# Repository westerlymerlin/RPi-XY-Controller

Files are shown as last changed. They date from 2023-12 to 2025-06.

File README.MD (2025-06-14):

# X-Y Controller

### X-Y Controller is a python app that can operate 24v stepper motors and is controlled via an HTTP API

Functional description and setup instructions are available in the file: [README.pdf](./README.pdf)

Python module documentation can be found in the folder: [docs](./docs/readme.md)

Change log can be found in the file [changelog.txt](./changelog.txt)

`app.py`			    Flask application that manages the API 

----------------------------------------------------

`stepperontrol.py`		Controls X-Y stage via bipolar stepper motors and an ADC controller to read positional information. 

### JSON Commands

`{'getxystatus', 1}` Return the current locations of the x and y steppers
 
`{'xmove', n}` move x stepper n steps (-n for backwards) (if n=0 then stop)

`{'ymove', n}` move y stepper n steps (-n for backwards) (if n=0 then stop)

`{'xmoveto', f}` move x stepper to position f (float)

`{'ymoveto', f}` move y stepper to position f (float)

&nbsp;   
&nbsp;    
&nbsp;  
&nbsp;   
&nbsp;   
&nbsp;   
--------------

#### Copyright (C) 2025 Gary Twinn

This program is free software: you can redistribute it and/or modify  
it under the terms of the GNU General Public License as published by  
the Free Software Foundation, either version 3 of the License, or  
(at your option) any later version.  

This program is distributed in the hope that it will be useful,  
but WITHOUT ANY WARRANTY; without even the implied warranty of  
MERCHANTABILITY or FITNESS FOR A PARTICULAR PURPOSE. See the  
GNU General Public License for more details.  

You should have received a copy of the GNU General Public License  
along with this program. If not, see <https://www.gnu.org/licenses/>.

Author:  Gary Twinn  
Repository:  [github.com/westerlymerlin](https://github)

-------------

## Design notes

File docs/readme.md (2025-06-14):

# Module Documentation

This document contains the documentation for all the modules in this project.

---

## Contents

[app](./app.md)  
X-Y Controller Web Application

A Flask-based web application that provides both a user interface and API endpoints
for controlling and monitoring an X-Y positioning system. The application offers:

- Status monitoring via web interface
- API endpoints for programmatic control (API key required)
- Self-test functionality for system validation
- Access to various log files (application, Gunicorn, system)
- System information including CPU temperature and running threads

The application is designed to be run by Gunicorn in a production environment,
but can also be run directly for development purposes.

Routes:
  - / : Main status page
  - /api : API endpoint for programmatic control (POST, requires API key)
  - /selftest : Runs a system self-test
  - /pylog : Displays application logs
  - /guaccesslog : Displays Gunicorn access logs
  - /guerrorlog : Displays Gunicorn error logs
  - /syslog : Displays system logs

Configuration is managed through settings imported from app_control.

[app_control](./app_control.md)  
Settings module, reads the settings from a settings.json file. If it does not exist or a new setting
has appeared it will creat from the defaults in the initialise function.

[logmanager](./logmanager.md)  
logmanager, setus up application logging. use the **logger** property to
write to the log.

[steppercontrol](./steppercontrol.md)  
Stepper Motor Control System for XY Table

This module provides classes and functions to control an XY positioning table
using stepper motors with ADC feedback for position tracking. It includes:

- Position tracking via ADC readings
- Stepper motor control with multiple movement modes (step, continuous, targeted)
- Web API endpoints for remote control
- Self-test capabilities for system diagnostics

The system uses GPIO pins on a Raspberry Pi to control the stepper motors and
reads position data through an ADC interface. It supports both programmatic
control and web-based interaction through status reporting functions.

Dependencies:
    - RPi.GPIO: For GPIO control
    - ADCPi: For analog position reading
    - threading: For non-blocking motor control

---

-------
#### Copyright (C) 2025 Gary Twinn  

This program is free software: you can redistribute it and/or modify
it under the terms of the GNU General Public License as published by
the Free Software Foundation, either version 3 of the License, or
(at your option) any later version.

This program is distributed in the hope that it will be useful,
but WITHOUT ANY WARRANTY; without even the implied warranty of
MERCHANTABILITY or FITNESS FOR A PARTICULAR PURPOSE. See the
GNU General Public License for more details.  
  
You should have received a copy of the GNU General Public License
along with this program. If not, see <https://www.gnu.org/licenses/>.  
  
  ##### Author: Gary Twinn  
  
 -------------

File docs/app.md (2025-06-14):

# None

# app

X-Y Controller Web Application

A Flask-based web application that provides both a user interface and API endpoints
for controlling and monitoring an X-Y positioning system. The application offers:

- Status monitoring via web interface
- API endpoints for programmatic control (API key required)
- Self-test functionality for system validation
- Access to various log files (application, Gunicorn, system)
- System information including CPU temperature and running threads

The application is designed to be run by Gunicorn in a production environment,
but can also be run directly for development purposes.

Routes:
  - / : Main status page
  - /api : API endpoint for programmatic control (POST, requires API key)
  - /selftest : Runs a system self-test
  - /pylog : Displays application logs
  - /guaccesslog : Displays Gunicorn access logs
  - /guerrorlog : Displays Gunicorn error logs
  - /syslog : Displays system logs

Configuration is managed through settings imported from app_control.

## subprocess

## enumerate\_threads

## Flask

## render\_template

## jsonify

## request

## httpstatus

## parsecontrol

## apistatus

## runselftest

## VERSION

## settings

## logger

#### app

#### read\_cpu\_temperature

```python
def read_cpu_temperature()
```

Reads the CPU temperature from the file specified in the settings and converts
it to Celsius.

Reads the raw CPU temperature value from the file path defined in the settings
dictionary under the 'cputemp' key. The value is retrieved as a string,
converted to a floating-point number, divided by 1000 to get the temperature
in Celsius, rounded to one decimal place, and returned.

Returns:
    float: The CPU temperature in Celsius.

Raises:
    KeyError: If the 'cputemp' key is missing from the settings dictionary.
    FileNotFoundError: If the specified file does not exist.
    IOError: If there is an error reading the file.

#### read\_reversed\_lines

```python
def read_reversed_lines(path)
```

Reads lines from a file, reverses their order, and returns the reversed list of lines.

Summary:
This function reads all the lines from a specified file, reverses the order of those lines,
and returns the reversed list. The file is expected to be encoded in UTF-8.

Args:
    path (str): The path to the file from which lines will be read.

Returns:
    list[str]: A list containing the lines from the file in reversed order.

#### threadlister

```python
def threadlister()
```

Get the list of active threads with their names and native IDs.

This function gathers all currently active threads, retrieves their names
and native IDs, and organizes them into a list. Each thread is represented
as a sublist containing its name and native ID. This is useful for debugging
or monitoring thread activity in the application.

Returns:
    List[List[str, int]]: A list of active threads where each thread is
    represented as a list containing its name (str) and native ID (int).

#### index

```python
@app.route('/')
def index()
```

Handles the root route of the application, retrieves CPU temperature, and renders
the main index page with relevant data such as locations, application version,
CPU temperature, and active threads.

Returns:
    str: Rendered HTML template for the index page.

#### api

```python
@app.route('/api', methods=['POST'])
def api()
```

Handles API requests for executing commands on specific items by verifying the provided API key.

The function is intended to handle POST requests to the '/api' endpoint. It verifies the validity of the
API key provided in the request headers before processing the request. If the API key is valid, it extracts
the required parameters from the JSON payload (item and command), processes the command, and returns the API
status. If the key is missing or invalid, it logs the attempt and returns an appropriate HTTP response.

The function also handles malformed JSON messages gracefully by returning an error response.

Returns:
    JSONResponse: A JSON-formatted response containing the API status with a status code of 201 if the request
    is processed successfully.
    String: An error message with an appropriate HTTP status code if the API key is missing, invalid, or the
    request JSON is malformed.

#### selftest

```python
@app.route('/selftest')
def selftest()
```

Handles the self-test endpoint for a web application. This function triggers
a self-test operation to assess system functionality and provides a response
indicating that the test process has started. Users are instructed to review
logs and the front panel for results.

Returns
-------
str
    A message indicating that the self-test operation has started, along with
    a link to access system logs.

#### showplogs

```python
@app.route('/pylog')
def showplogs()
```

Handles the retrieval and rendering of application logs in reverse order.

This function is mapped to the '/pylog' endpoint and fetches the log entries
for a Data Node from the specified log file. The logs are reversed so that
recent entries are displayed first. It then renders an HTML template with
the logs, title, and version information, providing a user interface to
analyze the log data.

Returns:
    Response: Renders an HTML template populated with log data, log title,
              and version details.

#### showgalogs

```python
@app.route('/guaccesslog')
def showgalogs()
```

Displays the Gunicorn access log by reading and reversing the lines of the
log file. The log is formatted into a web page showing the most recent
entries first.

Returns
-------
str
    Rendered HTML template for displaying the Gunicorn access log.

Raises
------
KeyError
    If 'gunicornpath' is not defined in the settings dictionary.

#### showgelogs

```python
@app.route('/guerrorlog')
def showgelogs()
```

Displays the Gunicorn error log.

This function handles the web endpoint for retrieving and displaying the
Gunicorn error log file. It reads the log file in reverse order, formats
it, and renders it in an HTML page for easy viewing.

Returns:
    Response: A rendered HTML page containing the Gunicorn error log.

#### showslogs

```python
@app.route('/syslog')
def showslogs()
```

Display the Raspberry Pi system logs along with CPU temperature.

Opens and reads the system log file and CPU temperature from the specified
file path within the `settings` dictionary. Retrieves the most recent 200
log entries using the `journalctl` command. The log entries are reversed to
show the latest log entries first. The CPU temperature data is converted
and rounded to a single decimal point before being rendered in the HTML
template.

Raised exceptions during file access or subprocess execution are not
explicitly handled here.

Returns:
    flask.Response: Rendered HTML template containing system log entries,
    CPU temperature, and the software version.

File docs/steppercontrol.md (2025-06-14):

# None

# steppercontrol

Stepper Motor Control System for XY Table

This module provides classes and functions to control an XY positioning table
using stepper motors with ADC feedback for position tracking. It includes:

- Position tracking via ADC readings
- Stepper motor control with multiple movement modes (step, continuous, targeted)
- Web API endpoints for remote control
- Self-test capabilities for system diagnostics

The system uses GPIO pins on a Raspberry Pi to control the stepper motors and
reads position data through an ADC interface. It supports both programmatic
control and web-based interaction through status reporting functions.

Dependencies:
    - RPi.GPIO: For GPIO control
    - ADCPi: For analog position reading
    - threading: For non-blocking motor control

## sleep

## os

## Timer

## GPIO

## ADCPi

## logger

## PositionClass Objects

```python
class PositionClass()
```

Manages the x and y positions obtained from ADC readings.

The class periodically reads position values from ADC inputs and
provides the location data along specified axes. It initializes
and starts a timer thread to fetch the positional data continuously.

#### \_\_init\_\_

```python
def __init__()
```

#### getpositions

```python
def getpositions()
```

Reads positional voltage data from an ADC and calculates the x and y positions
relative to a 2.5V reference. This is a continuous process that updates the
object's x and y attributes every 0.25 seconds while the ADC object is valid.

#### location

```python
def location(table_axis)
```

Determines and returns the location value along a specified axis.

This method evaluates the given table axis ('x' or 'y') and
returns the corresponding coordinate value. If the provided axis
is invalid, a default value of -99.99 is returned.

Args:
    table_axis: A string indicating the axis ('x' or 'y').

Returns:
    float: The coordinate value for the specified axis, or -99.99
    if the axis is invalid.

## StepperClass Objects

```python
class StepperClass()
```

Represents a stepper motor controller, enabling precise control over the stepper
motor's movement, configuration, and operational parameters.

This class provides methods for initializing and controlling a stepper motor's
movement such as stepping forward, stepping backward, stopping, or moving to
specific positions. It also supports setting GPIO channels, retrieving active
sequences, and managing limits for motor movement. The class incorporates
adjustable movement speeds (full speed or slow) and ensures proper handling of
stepper sequences during operation.

Attributes:
    axis: A string indicating the axis of operation for the stepper motor.
    seq: A list of lists, defining sequences for stepper coil activations.
    channela: An integer representing the GPIO channel for the first winding.
    channelaa: An integer representing the GPIO channel for the second winding.
    channelb: An integer representing the GPIO channel for the third winding.
    channelbb: An integer representing the GPIO channel for the fourth winding.
    sequenceindex: An integer representing the current sequence index of the motor.
    upperlimit: A float defining the maximum allowed position limit for movement.
    lowerlimit: A float defining the minimum allowed position limit for movement.
    sequence: An integer counter for the current movement sequence.
    pulsewidth: A float specifying the delay between steps, controlling speed.
    moving: A boolean flag indicating whether the motor is actively moving.

#### \_\_init\_\_

```python
def __init__()
```

#### setchannels

```python
def setchannels(a, aa, b, bb)
```

Sets up the channel attributes and configures them as output channels.

This method assigns input values to the corresponding channel attributes of
the object and configures the specified GPIO channels as outputs using the
GPIO setup method.

Args:
    a: The first channel to be assigned to 'channela'.
    aa: The second channel to be assigned to 'channelaa'.
    b: The third channel to be assigned to 'channelb'.
    bb: The fourth channel to be assigned to 'channelbb'.

#### listchannels

```python
def listchannels()
```

Returns a list of available channels.

This method retrieves and returns a list of channels available
within the current instance. It consolidates the individual channel
attributes defined in the object.

Returns:
    list: A list containing elements channela, channelaa, channelb,
    and channelbb.

#### current

```python
def current()
```

Returns the current element from the sequence based on the sequence index.
It retrieves the element at the position indicated by 'sequenceindex' from
the sequence stored in 'seq'.

Returns:
    The element in the sequence located at the index defined by attribute 'sequenceindex'.

#### movenext

```python
def movenext(fine=False)
```

Moves the axis motor to the next position within the defined range of movement.

This method increments the motor's sequence index to move the axis one step forward,
provided the current position of the motor's axis is less than the specified upper limit.
The movement can be divided between fine and coarse categories
based on whether the `fine` parameter is set to True or False.

Parameters:
    fine (bool, optional): If True, retains output state after a movement;
                           otherwise, resets the output state to zero.

#### moveprevious

```python
def moveprevious(fine=False)
```

Moves to the previous position along a defined axis.

This function decreases the position index by one step unit and
updates the output according to the current sequence. The sequence index
is updated in a circular manner. If fine movement is not required,
the output is reset to neutral after the step.

Args:
    fine (bool): If True, the movement is fine and does not reset the output
                 to neutral after stepping. Defaults to False.

#### stop

```python
def stop()
```

Stops the current movement and updates the sequence counter.

Stops the movement of the device or component by setting its moving status to
False and increments the sequence number. Logs the current position of the
device/component on the x and y axes. Outputs a signal to indicate the stop
state.

#### move

```python
def move(steps)
```

Moves a mechanism a specified number of steps in a defined sequence. The movement
can be either forward or backward depending on whether the step count is positive
or negative. The function halts movement if steps reach zero or if the moving
state becomes false. It includes a sequence update and enforces a delay between
steps based on a pulse width.

Parameters:
    steps (int): The number of steps to move. Positive values indicate forward
    movement, and negative values indicate backward movement.

#### moveslow

```python
def moveslow(steps)
```

Moves the object step-by-step in a specified direction. The method continues moving
the object one step at a time until the specified number of steps is completed or
movement is explicitly stopped. Movement is paused for a fixed time interval after
each step to simulate slow movement.

Parameters:
    steps (int): The number of steps to move. Positive values indicate forward
    movement; negative values indicate backward movement.

#### moveto

```python
def moveto(target)
```

Moves the axis to the specified target position within predefined limits. The method adjusts
the axis position step by step until it reaches the target position or a defined condition
occurs, such as exceeding a step counter threshold or passing the target position.

If the target position is outside the lower and upper limits, the operation will not
proceed. Step adjustments are made iteratively to ensure the axis reaches the closest
possible location to the target. The sequence number ensures the operation is associated
with the intended move command and prevents interference from other simultaneous commands.

Parameters
----------
target : float
    The desired position to which the axis is moved.

#### output

```python
def output(channels)
```

Controls the output state of specified GPIO channels using the provided channel states.

This function takes a list or tuple of four channel states and sets the associated
GPIO output for each corresponding channel. Each state in the list corresponds to
a specific GPIO channel, and the function utilizes the `output` method of the
GPIO module for assigning these states.

#### httpstatus

```python
def httpstatus()
```

Provides a function to generate a list containing rounded positional status.

The `httpstatus` function creates a dictionary containing the keys `xpos` and `ypos`, where the values
are the rounded versions of `positions.x` and `positions.y` respectively.
It then adds this dictionary into a list and returns it as the function output.

Returns:
    list: A list with a single dictionary containing `xpos` and `ypos` keys, with their corresponding
    values being rounded to four decimal points.

#### apistatus

```python
def apistatus()
```

Retrieve the current status of the system including positions and movement states.

This function compiles the current x and y positions of the system, along with
the movement status of stepper motors for both axes, into a dictionary.

Returns:
    dict: A dictionary containing the x and y positions, as well as movement
    states for both stepper motors.

#### parsecontrol

```python
def parsecontrol(item, command)
```

Parses the control command and executes the corresponding action, such as
moving a stepper motor or issuing a system restart. The function supports
multiple control commands and executes them in separate timer threads when
required.

Parameters:
item (str): The control item indicating the action type, such as 'xmove',
'ymove', 'xmoveto', 'ymoveto', or 'restart'.
command (str): The associated command or argument required for the action.

#### runselftest

```python
def runselftest()
```

Stops both motors and initiates a test sequence with a delay.

This function ensures that the motors are stopped prior to running
the self-test, providing a safe starting point for the test. A delay
of 10 seconds is introduced before beginning the test sequence. The
test sequence is executed in a separate thread.

#### reboot

```python
def reboot()
```

Reboots the system using an operating system command.

This function logs a warning message indicating that the system is
restarting and then executes the system's reboot command immediately.
This operation requires appropriate system permissions.

#### testsequence

```python
def testsequence()
```

Conducts a self-test sequence for channel x and channel y operations, verifying stepper motor
behaviors through various output states and movement actions. The function performs a series
of tests on both channels by setting their output states, moving them in forward and backward
directions, and ensuring their responses align with expected behavior.

#### positions

#### stepperx

#### steppery

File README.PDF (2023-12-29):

# X-Y Controller

Software Functional Requirements

By Gary Twinn

## Contents

Operating system | Error! Bookmark not defined.
Run Operating System Updates | Error! Bookmark not defined.
Install PIP3 for Python 3.x installation | Error! Bookmark not defined.
Install Flask installation | Error! Bookmark not defined.
Install Raspberry Pi GPIO Driver | Error! Bookmark not defined.
Download the XY-Controller application | Error! Bookmark not defined.
Copy the python files to the Pi | Error! Bookmark not defined.
Nginx installation | Error! Bookmark not defined.
Gunicorn for Python 3.x installation | Error! Bookmark not defined.

## List of Figures

## List of Tables

## Overview

The X-Y controller software consists of a python (Python Software Foundation, 2020) application to control the 2 stepper motors on the X-Y Stage of the Helium line.

The X-Y table consists of 2 Bipolar stepper motors to drive the table in two dimensions. A stepper motor consists of a pair of windings A-AA and B-BB surrounding a rotor containing permanent magnets (Figure 1)

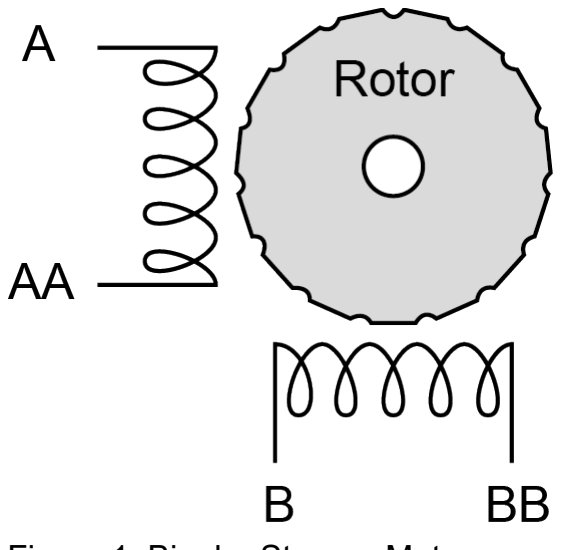
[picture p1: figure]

Figure 1: Bipolar Stepper Motor
The stepper motor is operated by applying a voltage across the A and B windings which causes the permanent magnets on the rotor to either attract or repel. The voltage is applied a with the positive to A and B and the negative to AA and BB. To move the rotor one winding will have the voltage reversed in turn. At each transition where the voltage is reversed on a winding the rotor will rotate 1.8° clockwise. By reversing the sequence the rotor will rotate anti-clockwise. By grounding both connections during of one winding between the reversals will cause the rotor to take a half step. Adding a delay between transitions will set a speed for the motor, a fast speed would have 25ms between transitions whereas a slower speed is used for accurately locating the laser over the sample.
A AA | B BB
0 | + | - | + | - Initial State
1 | + | - | - | + B reversal
2 | - | + | - | + A reversal
3 | - | + | + | - B revert
4 | + | - | + | - A revert
Table 1: Full step sequence for bipolar stepper motor

A AA | B BB
0 | + | - | + | - Initial State
1 | + | - | - | - ½ step ground B
2 | + | - | - | + B reversal
3 | - | - | - | + ½ step ground A
4 | - | + | - | + A reversal
5 | - | + | - | - ½ step ground B
6 | - | + | + | - B revert
7 | - | - | + | - ½ step ground A
8 | + | - | + | - A revert
Table 2: Half step sequence for bipolar stepper motor

There are two 2KΩ linear displacement sensors with a 50mm travel mounted on the x-y stage, one in each direction. By applying a voltage to each end of the sensor, the location of the wiper along the sensor can be determined. The travel along the planchet is 10.5mm in each of the X directions (from the origin) and 17.5mm from the origin in each of the Y directions.

The 2KΩ displacement sensor will have a reference voltage of +5.08 volts applied to one static connection, the other static connection will be held to 0V. That will give a voltage gradient along the 50mm of 0.1V per mm.

A joystick will be required for manual control of the X-Y table.
The computer required to control the valves will be a Raspberry Pi 4 (Raspberry PI Foundation, 2020), it will require a connector to break out the required 12 GPIO pins and connect to the driver boards.

Each stepper motor will be connected to 4 dedicated GPIO lines on the raspberry Pi computer. The valves run on 5V DC @ 1 A, so a driver circuit will be required to step up the voltage and current from the Pi. The linear

The Raspberry Pi computer will be controlled via a RESTful API listening on port 80 for a valid json message.

## Input Messages

Json messages in the following formats will be accepted:

Move in X direction to a location (voltage). Where n is a floating-point number between -2.5 and +2.5. Once started the stepper will move at a relative high speed (30 steps per second) until the position voltage is within 0.2V (~ 2mm) at which point it will slow to a rate of 10 steps a second until the position voltage is within 0.1V (~ 1mm). At 0.1V the rate will slow again to 3 steps per second until the desired position has just passed, at that point the stepper will reverse for 1 step to position as the table as accurately as possible with the stepper motors attached to the x-y stage.

{
"item": "xmoveto",
"command": n
}

Move in X direction nn steps. Where nn is a positive or negative integer depending on the direction or motor rotation. Sending a value of 0 will cause the stepper motor to halt immediately and disengage power to the x direction stepper motor.

{
"item": "xmove",
"command": nn
}

Move in Y direction to a location (voltage). Where n is a floating-point number between -2.5 and +2.5.

{
"item": "ymoveto",
"command": n
}

Move in Y direction nn steps. Where nn is a positive or negative integer depending on the direction or motor rotation. Sending a value of 0 will cause the stepper motor to halt immediately and disengage power to the y direction stepper motor.

{
"item": "ymove",
"command": nn
}

## Output Messages

Following any valid command, the following query is returned: (ss = open or closed)

{
"xpos": xnn,
"ypos": ynn
}

Where xnn and ynn are floating point numbers denoting the output voltages of each displacement sensor.

## Control to GPIO assignment

Control | Designation | Connector | Designation | Control
| 3v3 | 1 | 2 | 5v
i2c Data | GPIO 02 | 3 | 4 | 5v
i2c Clock | GPIO 03 | 5 | 6 | GND
GP clock | GPIO 04 | 7 | 8 | GPIO 14
| GND | 9 | 10 | GPIO 15
X Stepper A | GPIO 17 | 11 | 12 | GPIO 18 | Y Stepper A
X Stepper AA | GPIO 27 | 13 | 14 | GND
X Stepper B | GPIO 22 | 15 | 16 | GPIO 23 | Y Stepper AA
| 3v3 | 17 | 18 | GPIO 24 | Y Stepper B
| GPIO 10 | 19 | 20 | GND
Y Stepper BB | GPIO 09 | 21 | 22 | GPIO 25
Joystick X+ | GPIO 11 | 23 | 24 | GPIO 08
| GND | 25 | 26 | GPIO 07
| GPIO 00 | 27 | 28 | GPIO 01
| GPIO 05 | 29 | 30 | GND
| GPIO 06 | 31 | 32 | GPIO 12 | Ready LED
X Stepper BB | GPIO 13 | 33 | 34 | GND
| GPIO 19 | 35 | 36 | GPIO 16 | Joystick X-
Joystick Speed | GPIO 26 | 37 | 38 | GPIO 20 | Joystick Y+
| GND | 39 | 40 | GPIO 21 | Joystick Y-
Table 3: Control to GPIO Assignments
The above assignments are based on a raspberry Pi 4B. GPIO channels in green are available and remain at 0v during the Pi boot up.

Once the boot sequence has completed and the software has started the final command on the initialising function will be to light the “Ready LED” to give a visual indication the raspberry PI has booted and is ready to accept commands on the REST api.

The Joystick connections will need to be set to inputs with an internal pull-up resistor, thus requiring a connection to GND in order to trigger movement.

## Driver circuit and power supply

The Pi 4B uses a 5v power supply provided via a USB-C connector. A 5V power supply rated at 3A will be required.

The GPIO outputs are 3.3v at 50mA, the stepper motors require 5V DC @1A to rotate but the current could increase above 1A under a heavy load. In order to drive the 4 windings in the stepper motors a driver circuit will be required to step up the voltage and current (Figure 2). A power supply with a continuous rating of 6.0A will be required to ensure reliability. To protect the Pi Zero from any voltage spikes that may be generated by the steppers, or a faulty component on the hight voltage/high current side of the driver, an opto-isolator will be required to provide full electrical isolation between the Pi and the driver circuit.

The stepper motors will be driven via an integrated circuit containing four Metal Oxide Field Effect Transistors (MOSFET). MOSFETs have a very low forward voltage once switched on and have a high-power capacity. As the stepper windings are inductive loads, when the power is removed from the windings there is a chance voltage spikes will be induced into the circuit so a Schottky diode will protect the MOSFET and opto-isolator.

An analogue to digital convertor will be required to read the voltage from the position sensors and turn it into a signal the Raspberry Pi computer can read. The ADC chosen was from Able Electronics (Able Electronics UK 2020) and a resolution of 12 bits was chosen giving the controller the ability to detect 4096 voltage steps. Given that a 50mm travel on the position sensor would give a voltage reading between 0V and 5V the voltage to distance conversion is 0.1V / mm. Dividing the 5V supply by the step resolution steps gives 0.0012V per step or a resolution of 0.012 mm.

The driver circuits will need to be housed in an enclosure that has external connectors for the mains supply, ethernet cable and connectors for the x and y steppers, x and y position sensors and joystick cables. It must have ventilation holes to prevent the Raspberry Pi’s, power supplies or driver MOS-FET transistors overheating. Indicator lights should show the status of the 5v PSU for the Raspberry Pi, the 5V Stepper PSU and the ready light to show the software has started.

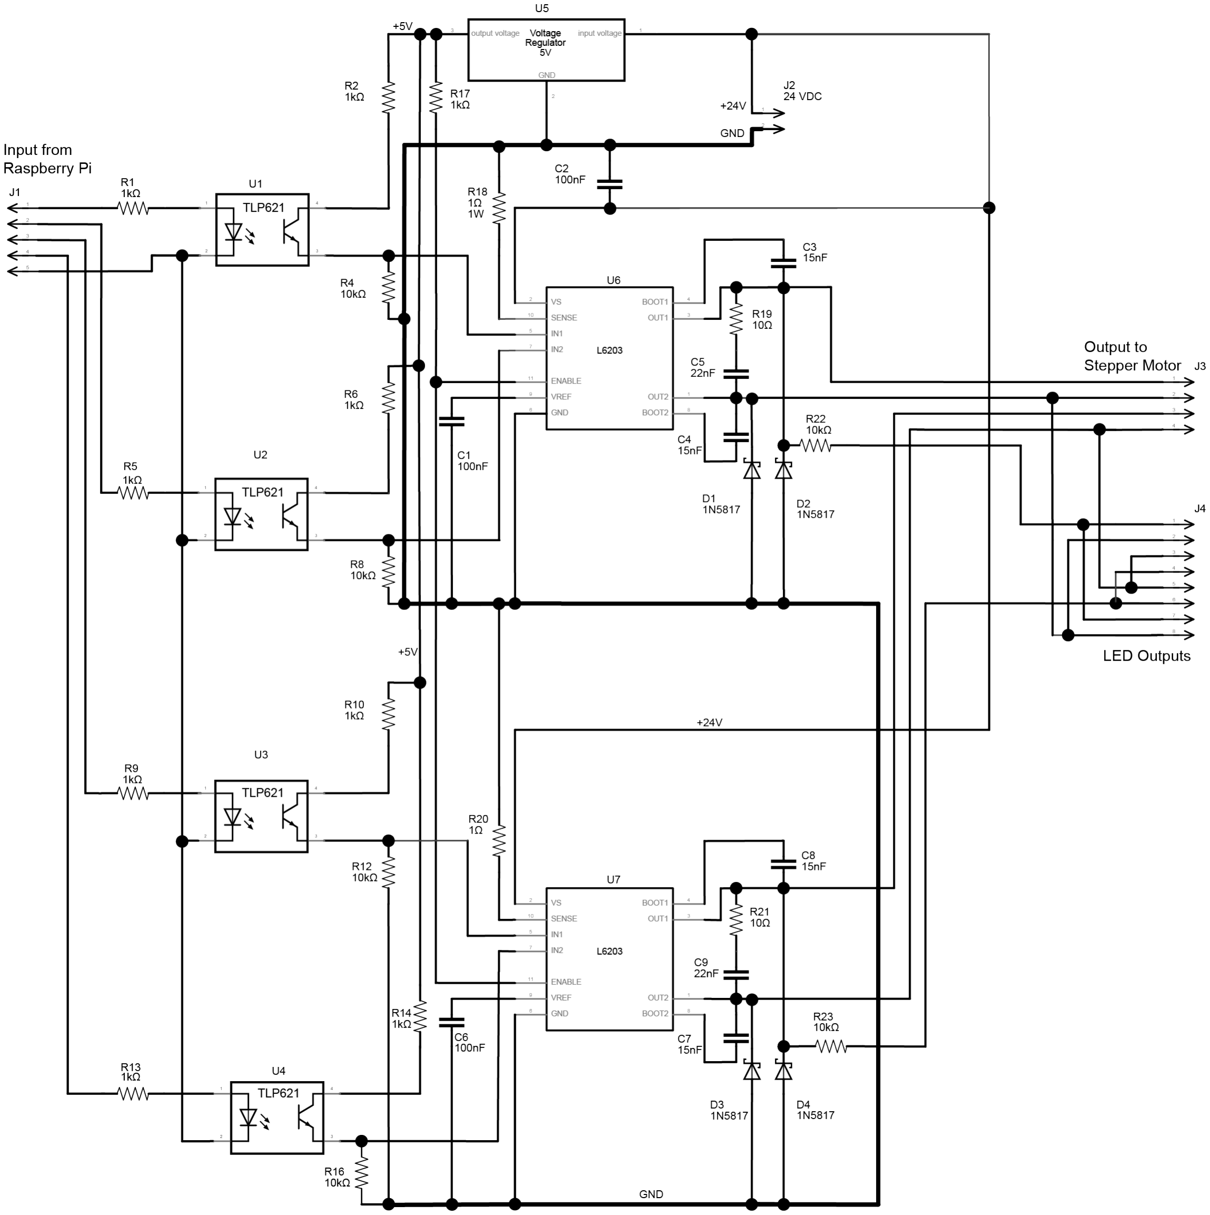
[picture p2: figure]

Figure 2: Schematic for a valve / stepper driver board

## Web interface

As well as accessing the status of the valves via the RESTful API a read-only web interface that can be accessed directly from a browser is will be available to view the valve status, application and web server logs.

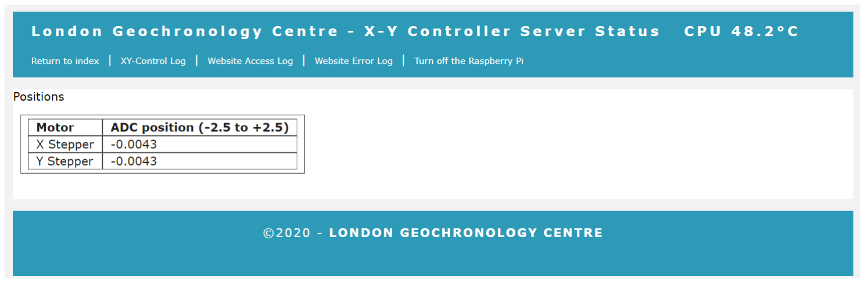
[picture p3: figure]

Figure 3: Web status page

## Interfaces

The connection from the back of the housing X and Y steppers, X and Y position sensors and Joysticks will be a standard 9pin D Plugs

## Stepper drive cable specification

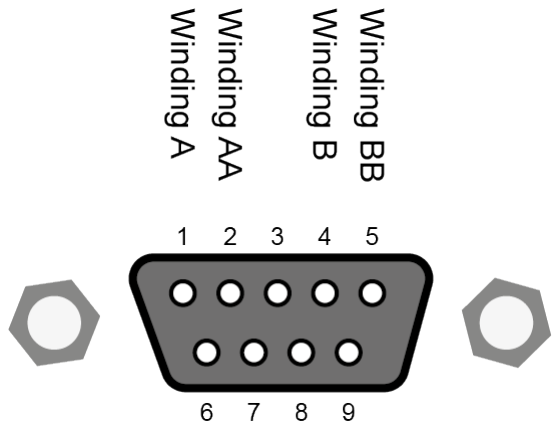
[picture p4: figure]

Figure 4: Stepper motor D plug assignments
The stepper drive cable consists of a male 9 pin D-plug for the controller connection, a 6 way cable with a minimum of a 1 amp capacity and a female 9 pin D-Plug for the stepper motor connector. Two cables are required, one for each stepper

## Position sensor cable specification

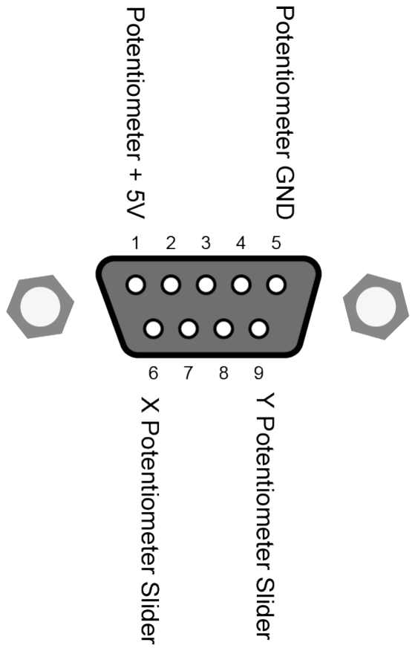
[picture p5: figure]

Figure 5: Position sensor D plug assignments
The position sensor cable consists of a male 9 pin D-plug for the controller connection, a 4 way shielded cable and a 4 pin DIN connector for the X-Y table connection.

## Joystick Connection Specification:

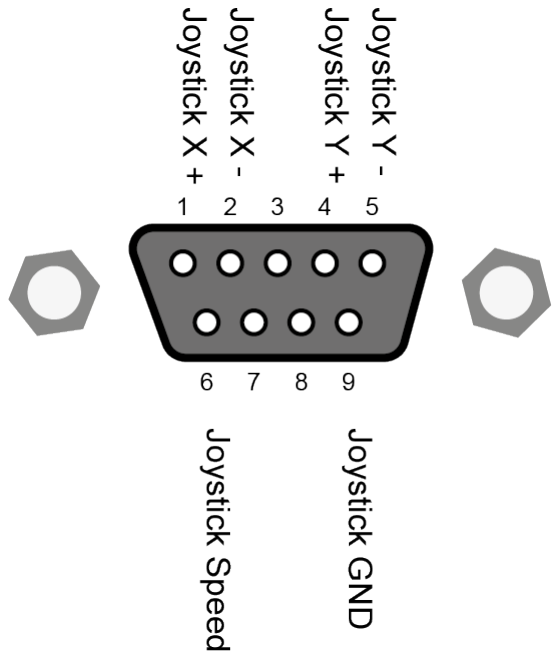
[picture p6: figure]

Figure 6: Joystick D plug assignments

## Operating System Installation

Use BalenaEtcher to install the latest version of the bookworm-lite 64bit operating system onto a 32Gb MicroMMC card.

Run the sudo raspi-config command to:
♦ enable ssh
♦ disable Serial
♦ enable 1²

C bus
♦ set the password on the pi user account to something other than “raspberry” ♦ change the GPU memory to 16Mb

## Software installation

## Run Operating System Updates

Run sudo apt update
Run sudo apt full-upgrade

## Install PIP3 for Python 3.x installation

Run sudo apt install python3-pip

## Nginx installation

Run sudo apt install nginx

## Install git and gh

Run sudo apt install git
Run sudo apt install gh
Run gh auth login
- What account do you want to log into? GitHub.com
- What is your preferred protocol for Git operations? HTTPS
- Authenticate Git with your GitHub credentials? (Y/n) y
- How would you like to authenticate GitHub CLI? Paste an authentication token

## Install SMBUS

Run sudo apt-get install python3-smbus
Run sudo apt-get install i2c-tools

Check that the ADC is connected and working:
Run sudo i2cdetect -y 1
You should get an output like:

0 1 2 3 4 5 6 7 8 9 a b c d e f
00: | -- -- -- -- -- -- -- -- -- -- -- -- --
10: -- -- -- -- -- -- -- -- -- -- -- -- -- -- -- --20: -- -- -- -- -- -- -- -- -- -- -- -- -- -- -- --30: -- -- -- -- -- -- -- -- -- -- -- -- -- -- -- --40: -- -- -- -- -- -- -- -- -- -- -- -- -- -- -- --50: -- -- -- -- -- -- -- -- -- -- -- -- -- -- -- --60: -- -- -- -- -- -- -- -- 68 69 -- -- -- -- -- --
70: -- -- -- -- -- -- -- --

## Configure git and download the X-Y controller code

Create a GitHub folder
Run mkdir github
Run cd github

Clone the repo
Run git clone https://github.com/westerlymerlin/UCL-RPi-XY-Controller.git

Copy the files to the home folder
Run cp -r ~/github/UCL-RPi-XY-Controller/* ~/

Set the execute flag on the scripts
Run chmod 755 ~/bin/*

Copy the Raspberry pi config files to the etc folder Run sudo cp -r ~/raspberry-pi/etc/* /etc

Reboot the Raspberry pi
Run sudo reboot

After the reboot a warning banner will appear at ssh logon.

## Install the flask libraries

Run sudo pip install flask --break-system-packages

## Install SMBUS

Run sudo pip install smbus2 --break-system-packages

## Nginx Configuration

Change directory to /etc/nginx/sites-enabled/
Run sudo rm default
Run sudo ln -s /etc/nginx/sites-available/lasercontroller

## Gunicorn for Python 3.x installation

Run sudo apt install gunicorn3
Run sudo systemctl enable gunicorn
Run sudo systemctl start gunicorn

Reboot the Raspberry pi
Run sudo reboot

If flask is installed, the python files are in the /home/pi directory, gunicorn3 is installed and configured and nginx is installed and configured the web service should be running and the site will be accessible on http://ip address of the server

## References

Able Electronics UK (2020) ADC Pi. Available online: https://www.abelectronics.co.uk/p/69/adc-pi-raspberry-pi-analogue-to-digital-converter (https://www.abelectronics.co.uk/p/69/adc-pi-raspberry-pi-analogue-to-digital-converter) [Accessed July 2020].
Python Software Foundation (2020) Python 3 Programming Language. Online. Available online: https://www.python.org [Accessed July 2020].
Raspberry PI Foundation (2020) Raspberry PI Model 4B Reference. Available online: https://www.raspberrypi.org/products/raspberry-pi-4-model-b/ [Accessed July 2020].

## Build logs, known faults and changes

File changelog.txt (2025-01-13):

2.1.3  BUG FIX system log viewer needs full path to work
2.1.2  Change to index page table
2.1.1  Removal of Joystick handler
2.1.0  Change to use Python venv environment
2.0.6  Bugfix API Key
2.0.5  Addedd API Key
2.0.4  Updates following static code analysis
2.0.3  Updates following static code analysis
2.0.2  Updated web interface and documentation updates
2.0.1  Updated web interface
2.0.0  Updated web interface
1.10.0 Added api command to restart pi
1.9.1  Added software version to status pages
1.9.0  bug fix
1.9.0  Added xmoving and ymoving data to api json message added system version into html pages added syslog html page
1.8.1  Updated to use json file for settings
1.8.0  Updated to use json file for settings

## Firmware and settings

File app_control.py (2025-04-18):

"""
Settings module, reads the settings from a settings.json file. If it does not exist or a new setting
has appeared it will creat from the defaults in the initialise function.
"""
import random
import json
from datetime import datetime

VERSION = '2.1.3'

def initialise():
    """Setup the settings structure with default values"""
    isettings = {'LastSave': '01/01/2000 00:00:01',
                 'app-name': 'Helium Line XY Controler',
                 'api-key': 'change-me',
                 'logfilepath': './logs/xycontrol.log',
                 'logappname': 'XY-Control-Py',
                 'loglevel': 'INFO',
                 'gunicornpath': './logs/',
                 'cputemp': '/sys/class/thermal/thermal_zone0/temp'}
    return isettings


def generate_api_key(key_len):
    """generate a new api key"""
    allowed_characters = "ABCDEFGHJKLMNPQRSTUVWXYZ-+~abcdefghijkmnopqrstuvwxyz123456789"
    return ''.join(random.choice(allowed_characters) for _ in range(key_len))


def writesettings():
    """Write settings to json file"""
    settings['LastSave'] = datetime.now().strftime('%d/%m/%Y %H:%M:%S')
    with open('settings.json', 'w', encoding='utf-8') as outfile:
        json.dump(settings, outfile, indent=4, sort_keys=True)

def readsettings():
    """Read the json file"""
    try:
        with open('settings.json', 'r', encoding='utf-8') as json_file:
            jsettings = json.load(json_file)
            return jsettings
    except FileNotFoundError:
        print('File not found')
        return {}

def loadsettings():
    """Replace the default settings with thsoe from the json files"""
    global settings
    settingschanged = False
    fsettings = readsettings()
    for item in settings.keys():
        try:
            settings[item] = fsettings[item]
        except KeyError:
            print('settings[%s] Not found in json file using default' % item)
            settingschanged = True
    if settings['api-key'] == 'change-me':
        settings['api-key'] = generate_api_key(30)
        settingschanged = True
    if settingschanged:
        writesettings()


settings = initialise()
loadsettings()

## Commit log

2022-12-17 Documentation Updates
    [Stepper Control Circuit.fzz]
2023-12-28 2.0.0 Updated web interface
    [Stepper Control Circuit.fzz]
2024-02-26 2.0.6 Bugfix API Key
    [app.py]
2025-01-13 2.1.3 BUG FIX system log viewer needs full path to work
    [app.py, app_control.py]
